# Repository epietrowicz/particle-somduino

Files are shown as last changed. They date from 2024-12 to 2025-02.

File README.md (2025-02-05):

# Somduino
This is a sample design for a _mostly_ assembled PCB from a manufacturing service like JLCPCB, helping you get started with a custom SoM based design. The Somduino is an Arduino Uno form factor breakout board intended to work with either BSoM or MSoM Particle products.

particle-somduino-final

## Overview
The SoMduino has the following features:
- USB Type C connector for programming
    - This development board cannot be powered via USB and will require either a LiPo battery or a DC barrel jack connection.
- ON / OFF switch
- Mode & Reset switches
- RGB LED indicator
- 5-17V DC barrel jack connector for battery charging and normal operation
- Qwiic connector for I2C expansion
- Charging indicator LED
- Arduino Uno form factor for Arduino shield compatibility
  
particle-somduino-1

## BOM
You can find a complete list of LCSC parts used in the example design below:

| Designator | Quantity | Comment | LCSC Part # |
| --- | --- | --- | --- |
| D1 | 1 | LED RGB | C5342281 |
| D2 | 1 | LED Charging | C2297 |
| H1 | 1 | Threaded standoff | C2916321 |
| J1, J4 | 2 | 1x08 Header | C27438 |
| J2 | 1 | 1x10 Header | C5116489 |
| J3 | 1 | 1x06 Header | C40877 |
| J5 | 1 | Barrel Jack Power In | C720557 |
| J6 | 1 | 1x02 Battery connector | C295747 |
| J7 | 1 | 1x04 Qwiic connector | C160390 |
| J8 | 1 | USB-C connector | C5362630 |
| R1, R2, R3, R5 | 4 | 1k 0603 resistor | C21190 |
| R10, R9 | 2 | 5.1k 0603 resistor | C23186 |
| R4, R8 | 2 | 10k 0603 resistor | C15401 |
| R6, R7 | 2 | 4.7k 0603 resistor | C23162 |
| SW1, SW2 | 2 | Push button switch | C318884 |
| SW3 | 1 | Power switch | C963205 |
| U1 | 1 | M.2 connector for SoM | C2977809 |

The cost of the example design is $54.88 for 5 mostly assembled boards. All that remains is a Particle SoM and power module. It is worth noting that I did not choose to upgrade from the “economic assembly” for the threaded standoff and plan to hand assemble that component saving $25.



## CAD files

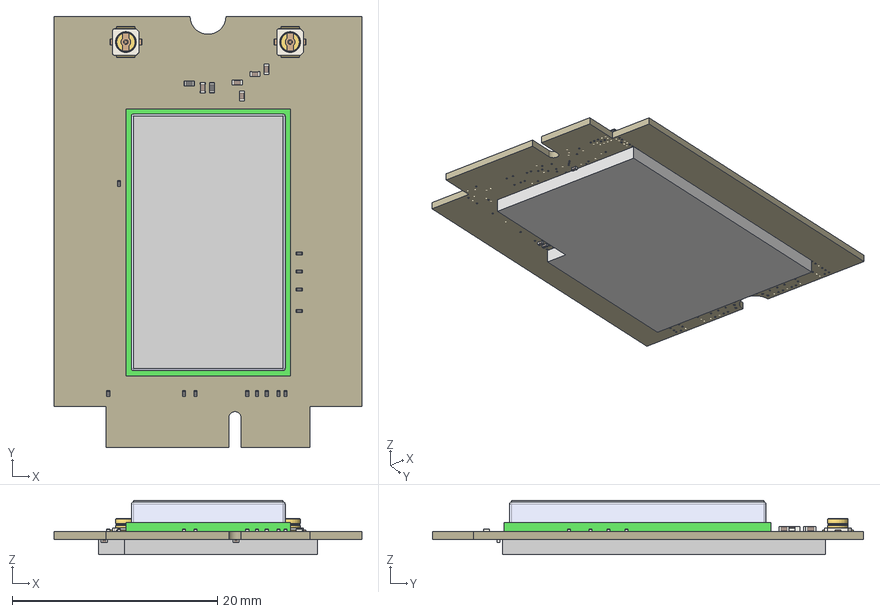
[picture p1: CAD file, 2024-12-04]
3D/B402.step
30.0 x 42.0 x 5.26 mm
Board
33pF x 8
1uF x 4
0.1uF
LQG15HS68NJ02 x 7
10uH
47pF x 35
BLM18EG221
Sara
Sara Product Label
IPEX-20279-001E
32.768kHz
IPEX-20279-001E_1
10K
DNP
0R x 12
10K_1
PESD0402MP

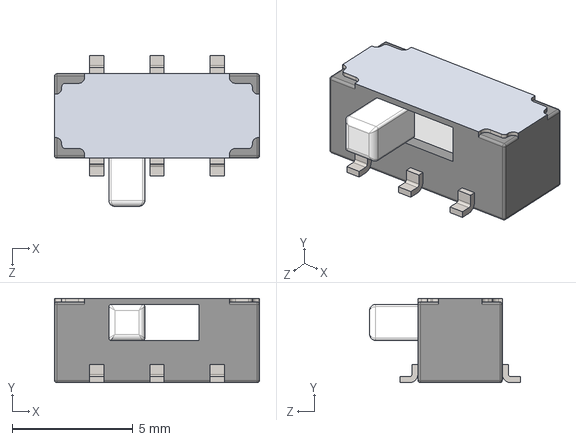
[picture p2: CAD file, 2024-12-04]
3D/CL-SB-22B-11.STEP
8.50 x 3.50 x 6.25 mm

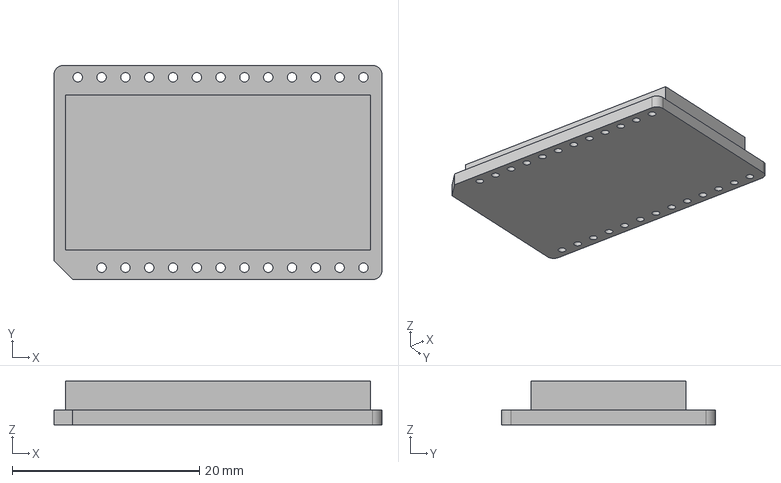
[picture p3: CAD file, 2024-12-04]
3D/ParticlePM-BAT.step
35.0 x 22.9 x 4.65 mm

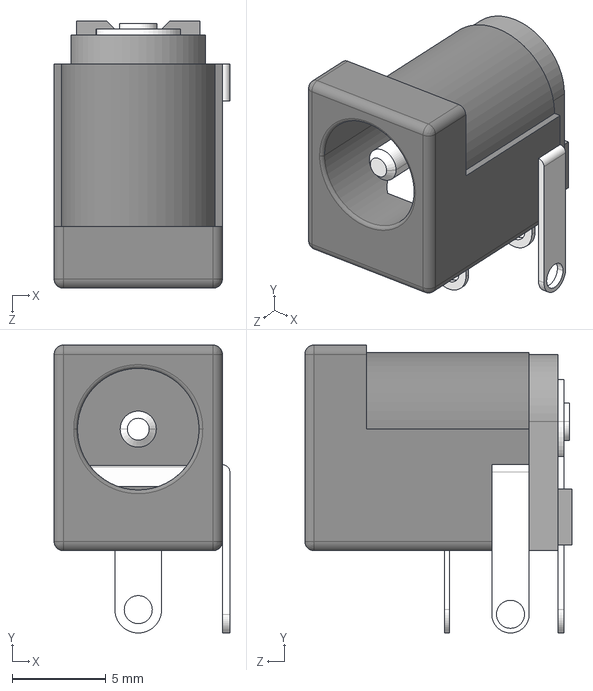
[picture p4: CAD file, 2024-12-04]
3D/DC-005.STEP
9.40 x 15.4 x 14.3 mm

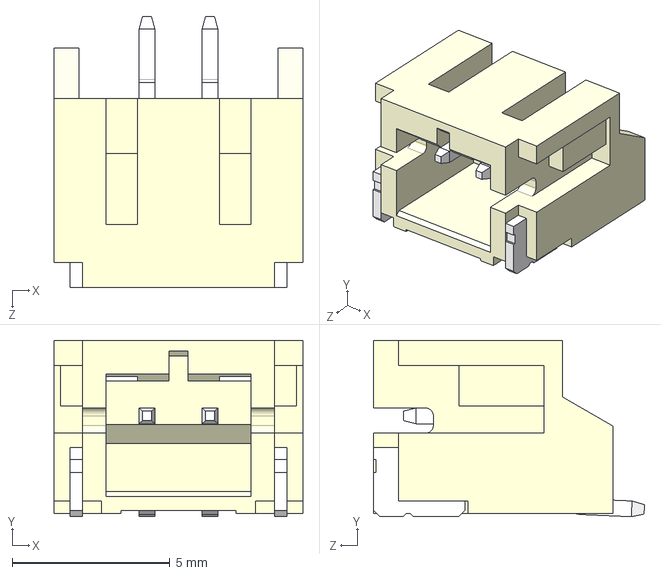
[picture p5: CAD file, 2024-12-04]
3D/S2B-PH-SM4-TB(LF)(SN)--3DModel-STEP-56544.STEP
7.90 x 5.60 x 8.60 mm

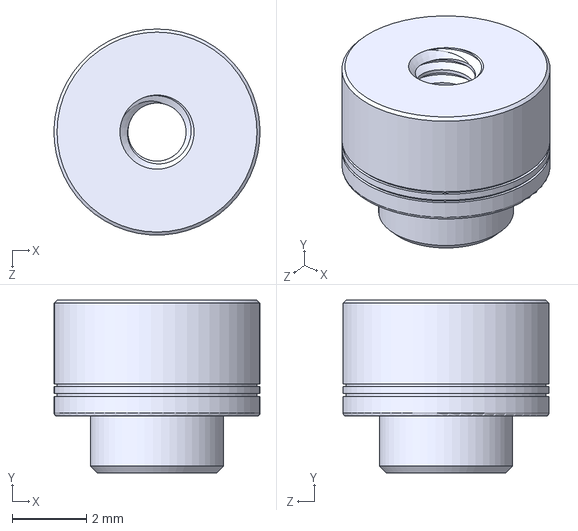
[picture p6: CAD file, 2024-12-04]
3D/SMTSO-M2-3ET--3DModel-STEP-56544.STEP
5.56 x 4.66 x 5.56 mm

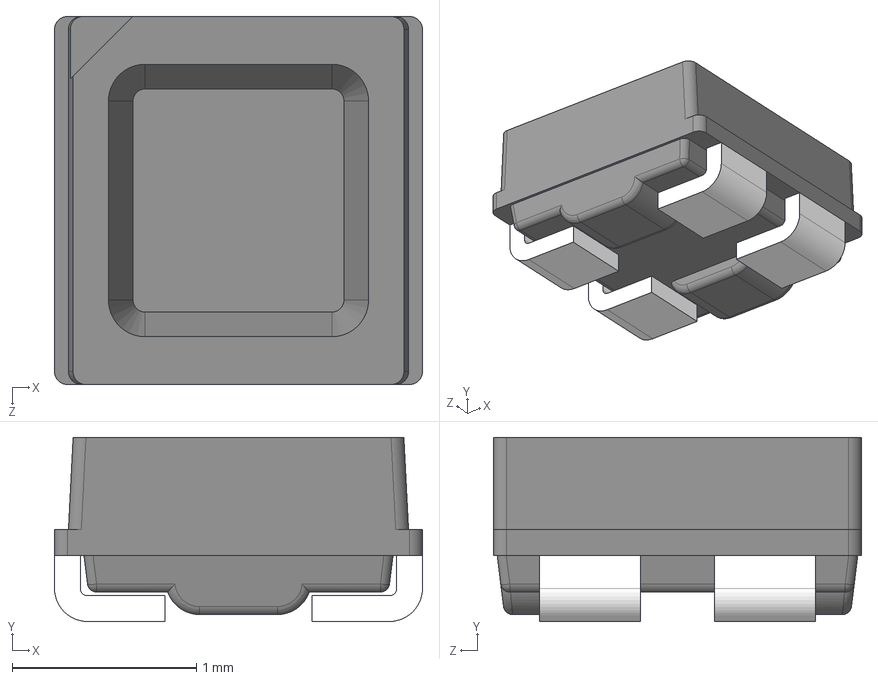
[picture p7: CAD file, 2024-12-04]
3D/CLMVC-FKA-CL1D1L71BB7C3C3.step
2.00 x 1.00 x 2.00 mm

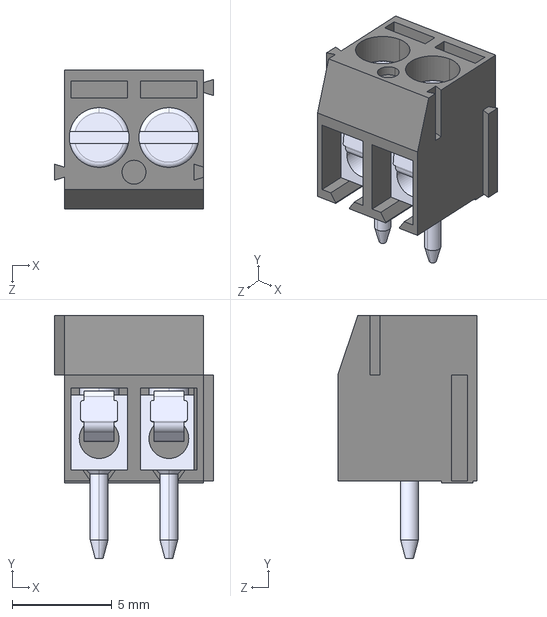
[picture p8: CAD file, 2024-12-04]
3D/OSTTE020104.step
8.00 x 12.2 x 7.00 mm

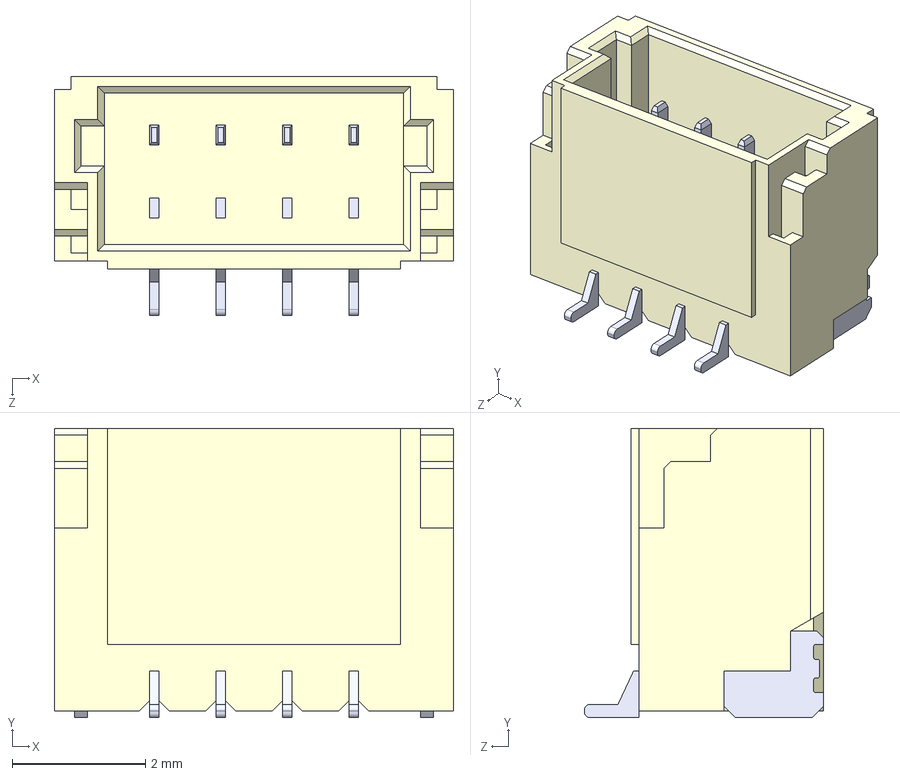
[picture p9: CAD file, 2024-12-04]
3D/BM04B-SRSS-TB-LF--SN---3DModel-STEP-56544.STEP
6.00 x 4.35 x 3.60 mm

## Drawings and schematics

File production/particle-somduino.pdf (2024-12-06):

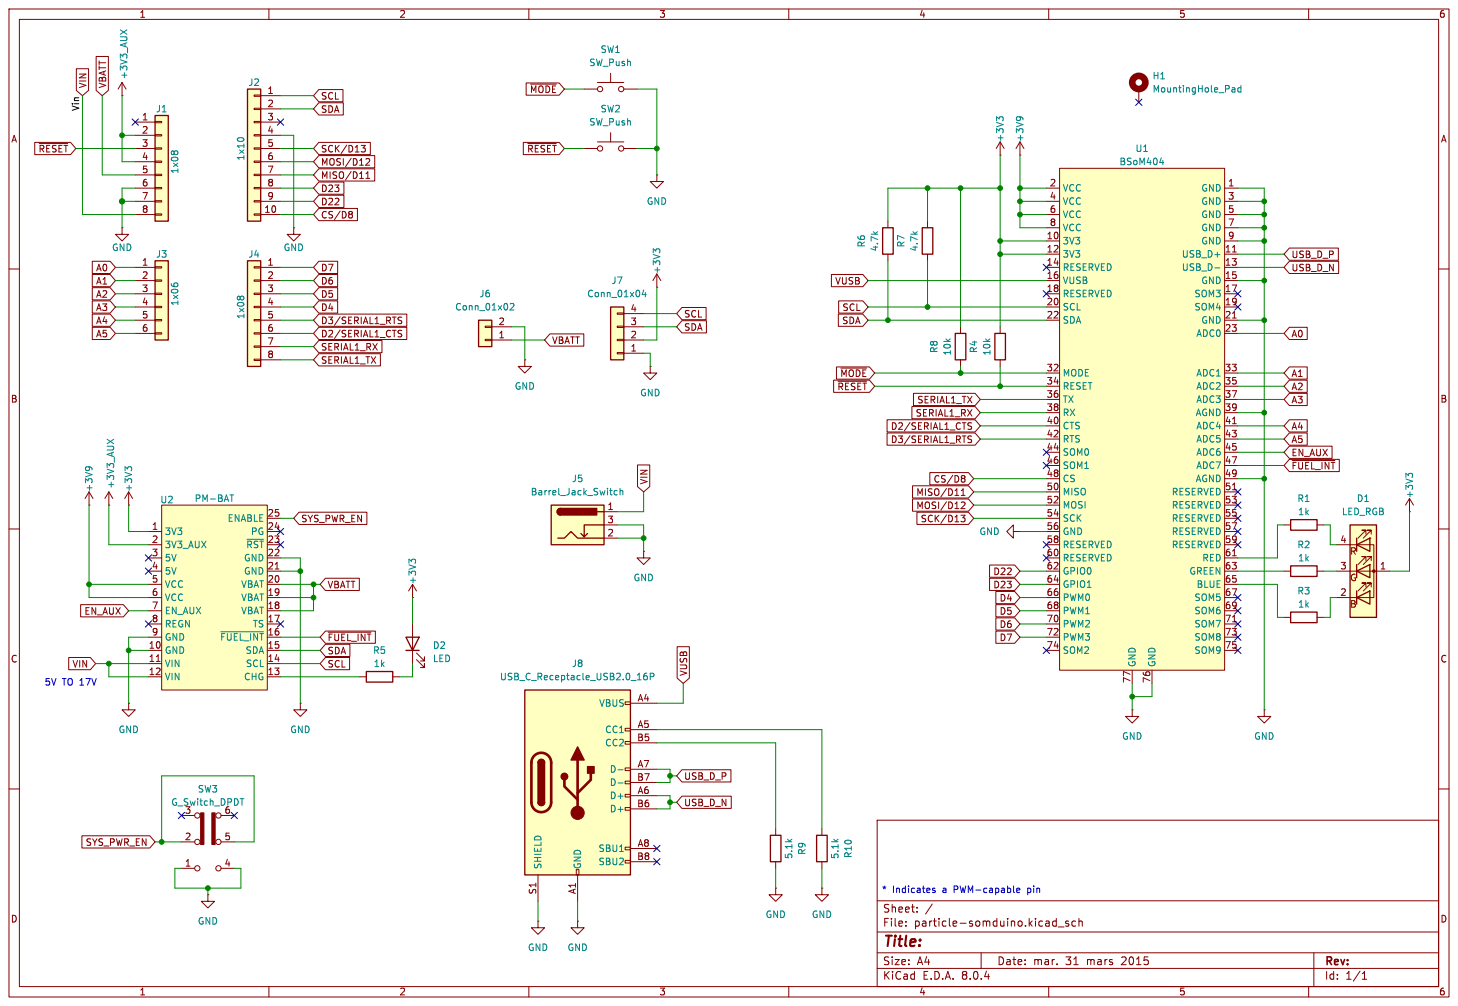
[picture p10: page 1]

Id: 1/1 Title: File: particle-somduino.kicad_sch Sheet: / GND

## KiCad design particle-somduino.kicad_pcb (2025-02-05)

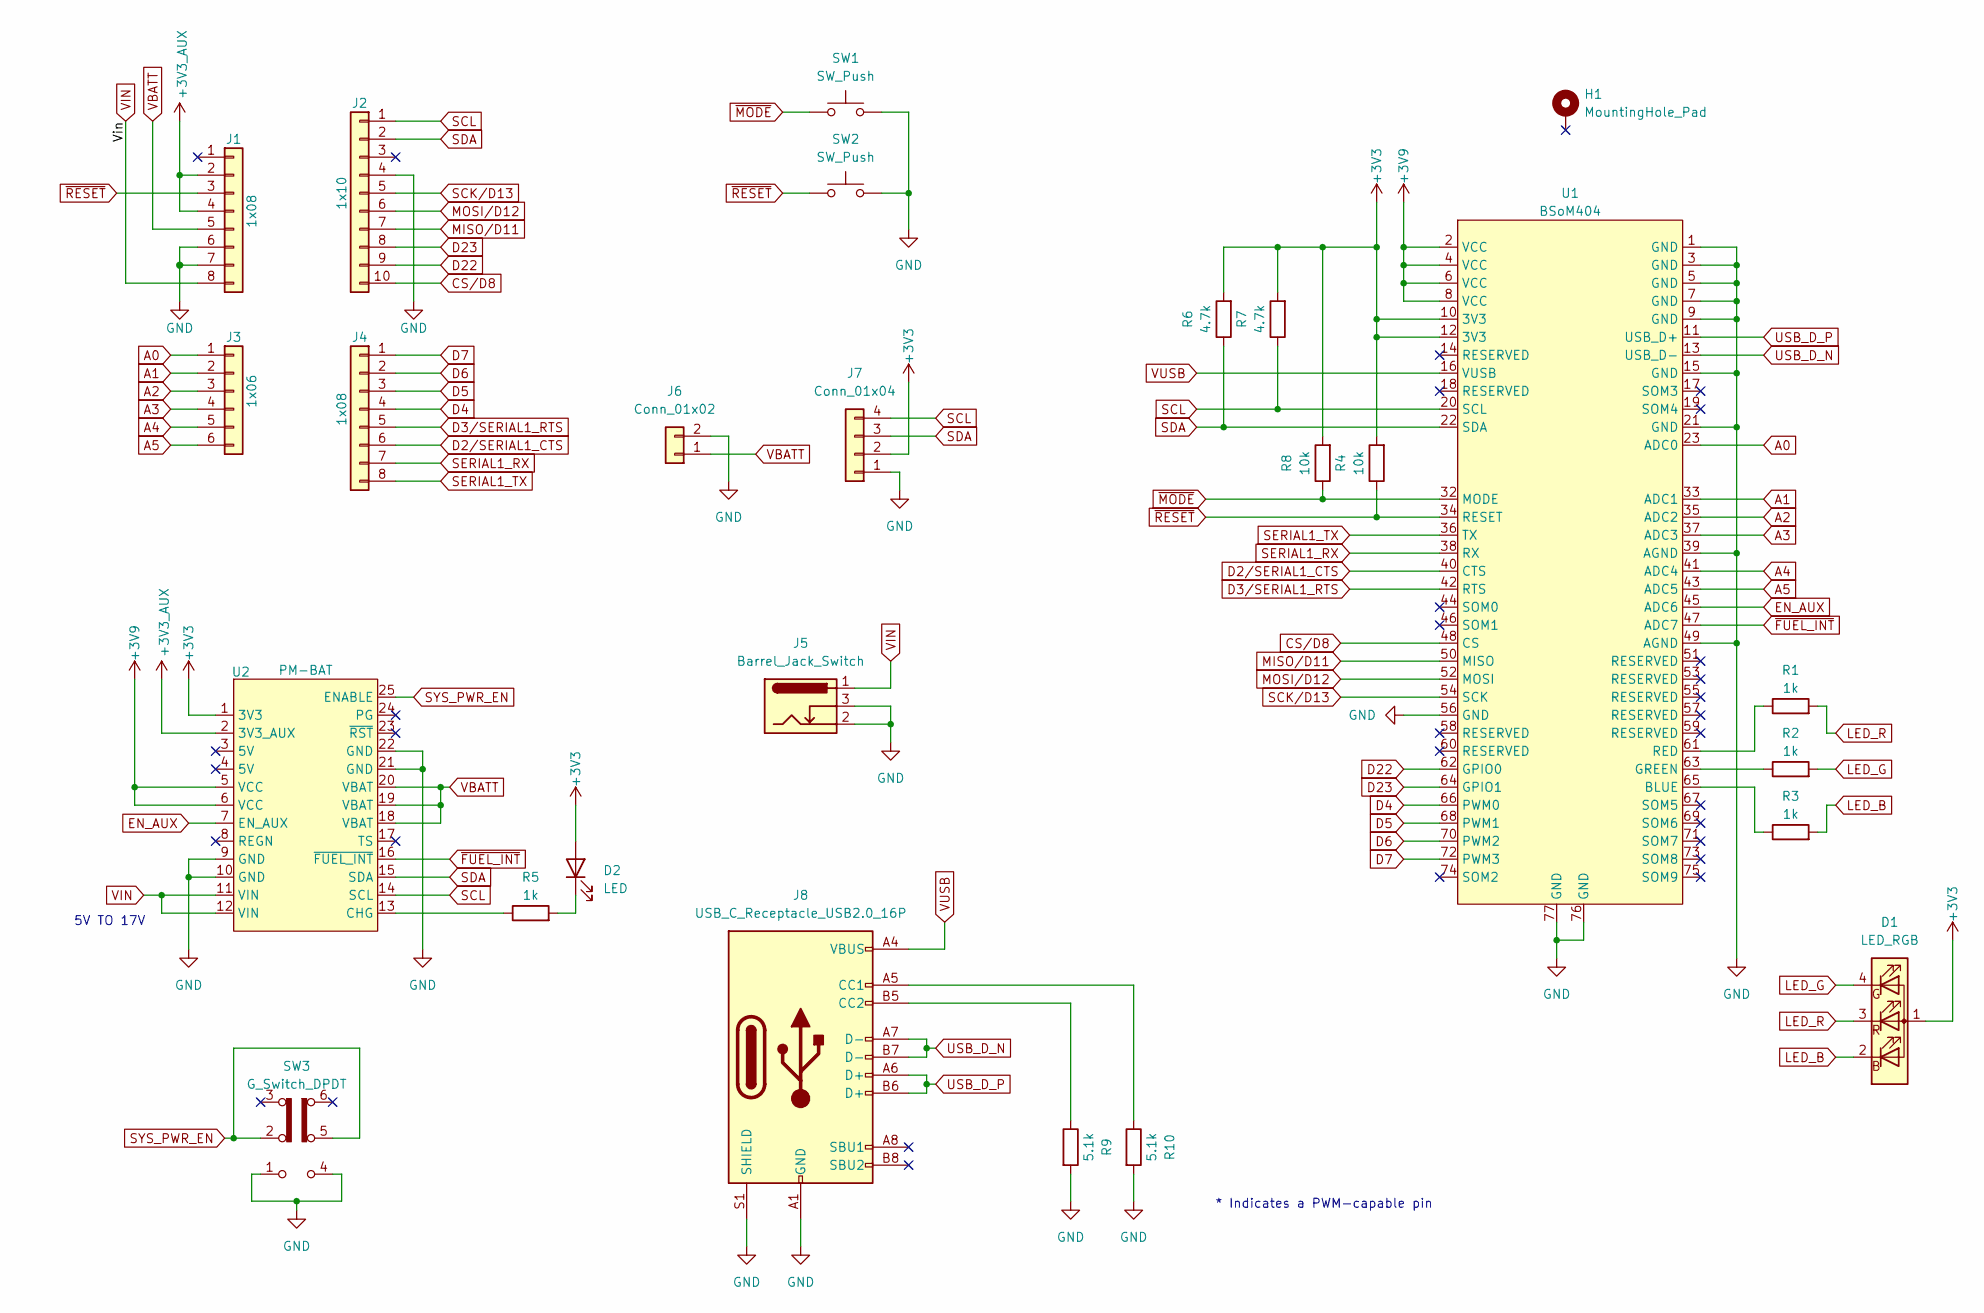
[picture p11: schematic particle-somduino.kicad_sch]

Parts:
D1: LED_RGB; LED_RGB_Wuerth-PLCC4_3.2x2.8mm_150141M173100; LCSC C5342281
D2: LED; LED_0805_2012Metric; LCSC C2297
H1: MountingHole_Pad; SoM_SMD_ThreadedStandoff; LCSC C2916321
J1, J4: 1x08; PinSocket_1x08_P2.54mm_Vertical; LCSC C27438
J2: 1x10; PinSocket_1x10_P2.54mm_Vertical; LCSC C5116489
J3: 1x06; PinSocket_1x06_P2.54mm_Vertical; LCSC C40877
J5: Barrel_Jack_Switch; DC-005-A200; LCSC C720557
J6: Conn_01x02; JST_PH_S2B-PH-SM4-TB_1x02-1MP_P2.00mm_Horizontal; LCSC C295747
J7: Conn_01x04; JST_SH_BM04B-SRSS-TB_1x04-1MP_P1.00mm_Vertical; LCSC C160390
J8: USB_C_Receptacle_USB2.0_16P; USB_C_Receptacle_G-Switch_GT-USB-7010i; LCSC C5362630
R1, R2, R3, R5: 1k; R_0603_1608Metric; LCSC C21190
R4, R8: 10k; R_0603_1608Metric; LCSC C15401
R6, R7: 4.7k; R_0603_1608Metric; LCSC C23162
R9, R10: 5.1k; R_0603_1608Metric; LCSC C23186
SW1, SW2: SW_Push; SW_Push_1P1T_XKB_TS-1187A; LCSC C318884
SW3: G_Switch_DPDT; G-Swtich_SW_DPDT; LCSC C963205
U1: BSoM404; SoM_M2_Connector; LCSC C2977809
U2: PM-BAT; ParticlePowerModuleSMD

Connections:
+3V3: D1.1 (A), D2.2 (A), J7.2, R4.2, R6.2, R7.2, R8.2, U1.10 (3V3), U1.12 (3V3), U2.1 (3V3)
+3V3_AUX: J1.2, J1.4, U2.2 (3V3_AUX)
+3V9: U1.2 (VCC), U1.4 (VCC), U1.6 (VCC), U1.8 (VCC), U2.5 (VCC), U2.6 (VCC)
A0: J3.1, U1.23 (ADC0)
A1: J3.2, U1.33 (ADC1)
A2: J3.3, U1.35 (ADC2)
A3: J3.4, U1.37 (ADC3)
A4: J3.5, U1.41 (ADC4)
A5: J3.6, U1.43 (ADC5)
CS/D8: J2.10, U1.48 (CS)
D2/SERIAL1_CTS: J4.6, U1.40 (CTS)
D3/SERIAL1_RTS: J4.5, U1.42 (RTS)
D4: J4.4, U1.66 (PWM0)
D5: J4.3, U1.68 (PWM1)
D6: J4.2, U1.70 (PWM2)
D7: J4.1, U1.72 (PWM3)
D22: J2.9, U1.62 (GPIO0)
D23: J2.8, U1.64 (GPIO1)
EN_AUX: U1.45 (ADC6), U2.7 (EN_AUX)
GND: J1.6, J1.7, J2.4, J5.2, J5.3, J6.2, J7.1, J8.A1 (GND), J8.A12 (GND), J8.B1 (GND), J8.B12 (GND), J8.S1 (SHIELD), R9.2, R10.2, SW1.2, SW2.2, SW3.1 (C), SW3.4 (A), U1.1 (GND), U1.3 (GND), U1.5 (GND), U1.7 (GND), U1.9 (GND), U1.15 (GND), U1.21 (GND), U1.39 (AGND), U1.49 (AGND), U1.56 (GND), U1.76 (GND), U1.77 (GND), U2.9 (GND), U2.10 (GND), U2.21 (GND), U2.22 (GND)
LED_B: D1.2 (BK), R3.2
LED_G: D1.4 (RK), R2.2
LED_R: D1.3 (GK), R1.2
MISO/D11: J2.7, U1.50 (MISO)
MOSI/D12: J2.6, U1.52 (MOSI)
unnamed: D2.1 (K), R5.2
unnamed: J8.A5 (CC1), R10.1
unnamed: J8.B5 (CC2), R9.1
unnamed: R3.1, U1.65 (BLUE)
unnamed: R2.1, U1.63 (GREEN)
unnamed: R1.1, U1.61 (RED)
unnamed: R5.1, U2.13 (CHG)
SCK/D13: J2.5, U1.54 (SCK)
SCL: J2.1, J7.4, R7.1, U1.20 (SCL), U2.14 (SCL)
SDA: J2.2, J7.3, R6.1, U1.22 (SDA), U2.15 (SDA)
SERIAL1_RX: J4.7, U1.38 (RX)
SERIAL1_TX: J4.8, U1.36 (TX)
SYS_PWR_EN: SW3.2 (B), SW3.5 (B), U2.25 (ENABLE)
USB_D_N: J8.A7 (D-), J8.B7 (D-), U1.13 (USB_D-)
USB_D_P: J8.A6 (D+), J8.B6 (D+), U1.11 (USB_D+)
VBATT: J1.5, J6.1, U2.18 (VBAT), U2.19 (VBAT), U2.20 (VBAT)
VIN: J1.8, J5.1, U2.11 (VIN), U2.12 (VIN)
VUSB: J8.A4 (VBUS), J8.A9 (VBUS), J8.B4 (VBUS), J8.B9 (VBUS), U1.16 (VUSB)
~FUEL_INT: U1.47 (ADC7), U2.16 (~FUEL_INT)
~MODE: R8.1, SW1.1, U1.32 (MODE)
~RESET: J1.3, R4.1, SW2.1, U1.34 (RESET)

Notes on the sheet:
5V TO 17V
* Indicates a PWM-capable pin

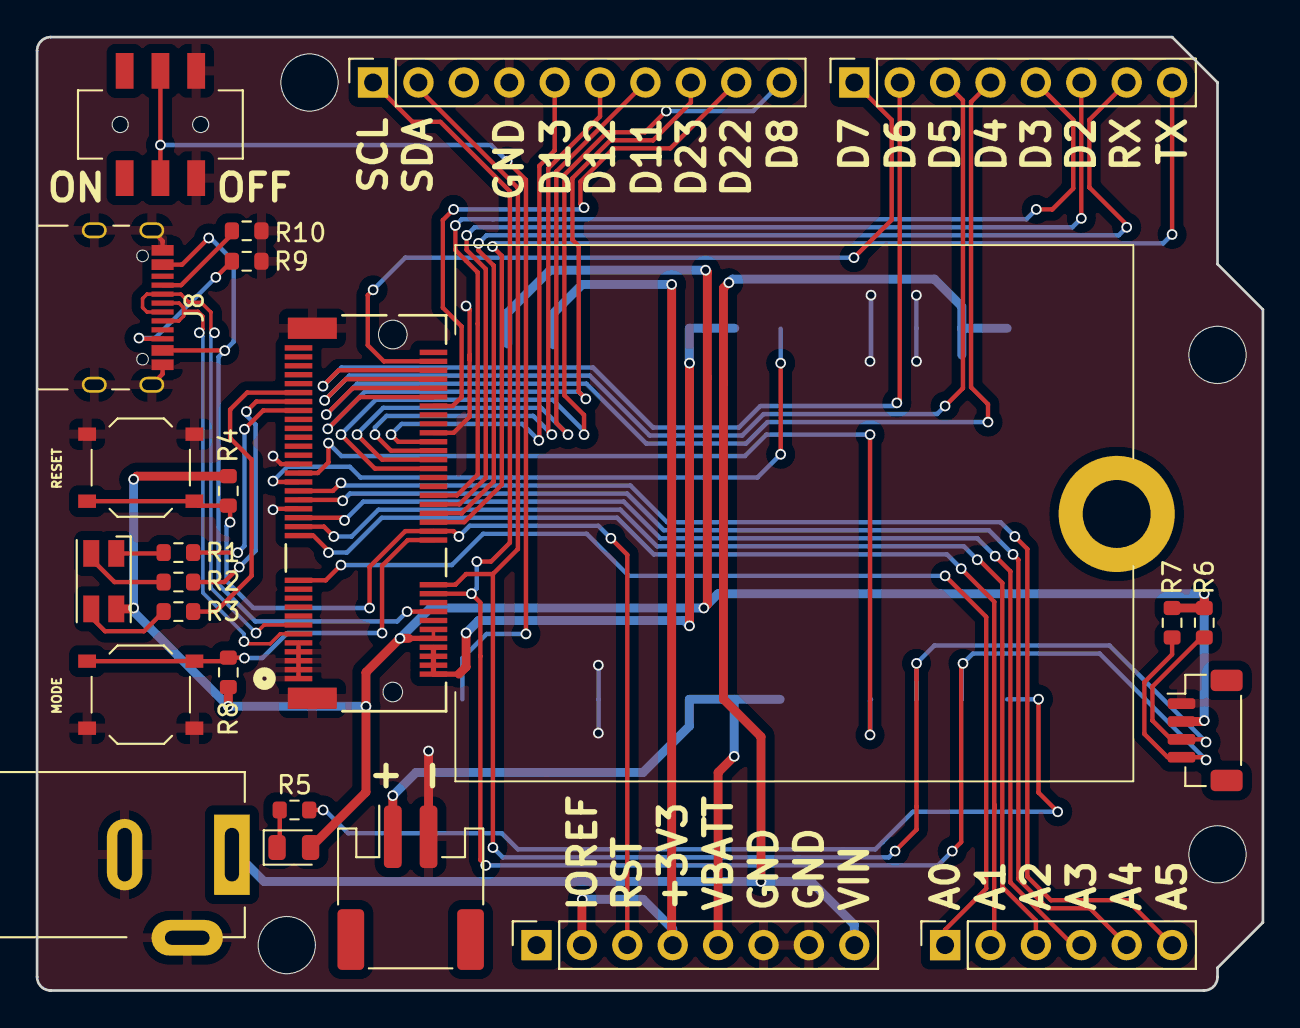
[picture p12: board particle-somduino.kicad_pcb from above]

Board: 2 copper layers, 68.6 x 53.3 mm, 30 parts (1 on the bottom side), 46 nets.

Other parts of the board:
MH1, MH2, MH3, MH4: MountingHole_3.2mm

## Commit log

2024-12-05 include bom files
    [bom.csv, designators.csv, positions.csv]
2024-12-05 reset gitignore
    [bom.csv, designators.csv, positions.csv]
